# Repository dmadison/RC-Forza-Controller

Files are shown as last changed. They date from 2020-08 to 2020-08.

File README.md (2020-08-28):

# RC Controller for Forza
This project converts a DUMBORC x4 remote control for an RC car into a controller for [Forza Horizon 4](https://forzamotorsport.net/en-us/games/fh4). A USB-capable microcontroller reads the receiver's PWM pulses and translates the signals into Xbox controller (XInput) inputs for the game.

For more information, check out the article on [PartsNotIncluded.com](https://www.partsnotincluded.com/modifying-an-rc-controller-to-play-forza-horizon).

## Dependencies
The microcontroller code has several dependencies:

* [ArduinoXInput](https://github.com/dmadison/ArduinoXInput) [(v1.2.3)](https://github.com/dmadison/ArduinoXInput/releases/tag/v1.2.3)
* [ServoInput](https://github.com/dmadison/ServoInput) [(v1.0.0)](https://github.com/dmadison/ServoInput/releases/tag/v1.0.0)
* [ArduinoXInput AVR Core](https://github.com/dmadison/ArduinoXInput_AVR) [(v1.0.1)](https://github.com/dmadison/ArduinoXInput_AVR/releases/tag/v1.0.1)

I've linked to the specific releases that work with this code. Note that other versions may not be compatible.

This project was compiled using version 1.8.12 of the Arduino IDE. Microcontrollers other than the ATmega32U4 may be compatible but have not been tested.

## License
This project is licensed under the terms of the [GNU General Public License](https://www.gnu.org/licenses/gpl-3.0.en.html), either version 3 of the License, or (at your option) any later version.

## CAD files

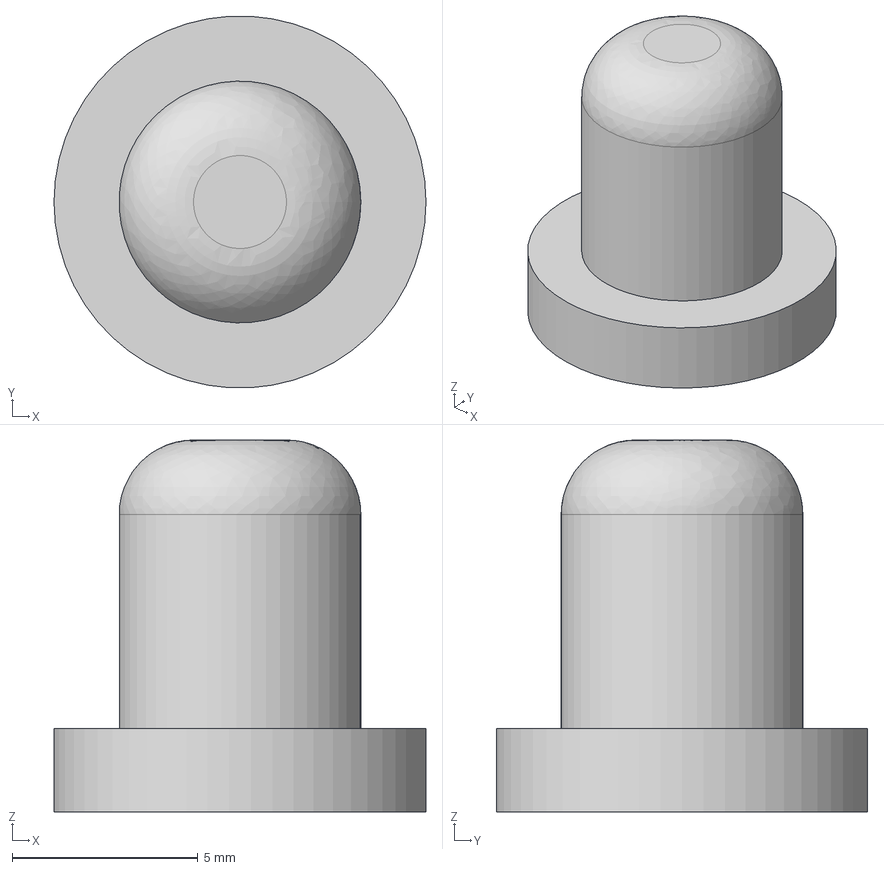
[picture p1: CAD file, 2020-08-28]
cad/CH 5-6 Button Insert/CH5-6 Button Insert.step
10.0 x 9.98 x 10.0 mm

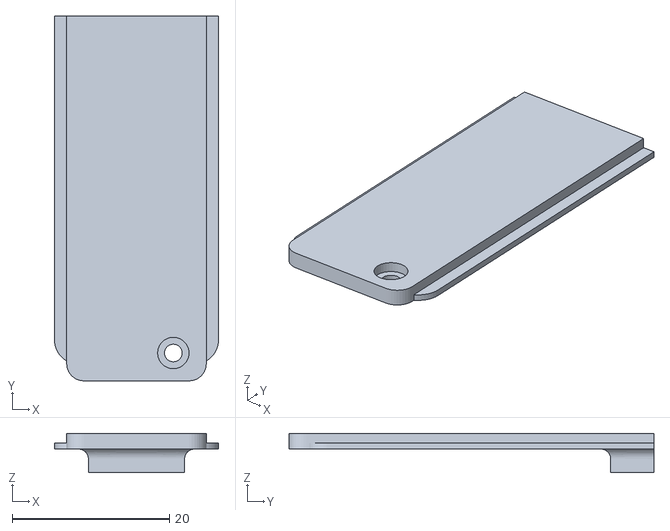
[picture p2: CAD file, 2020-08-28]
cad/Receiver Case/RC-Receiver_Cover.stl
20.9 x 46.4 x 5.00

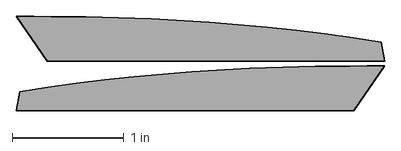
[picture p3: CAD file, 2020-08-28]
decals/DumboRC_Grip-Base-Strip.dxf
3.30 x 0.843 in

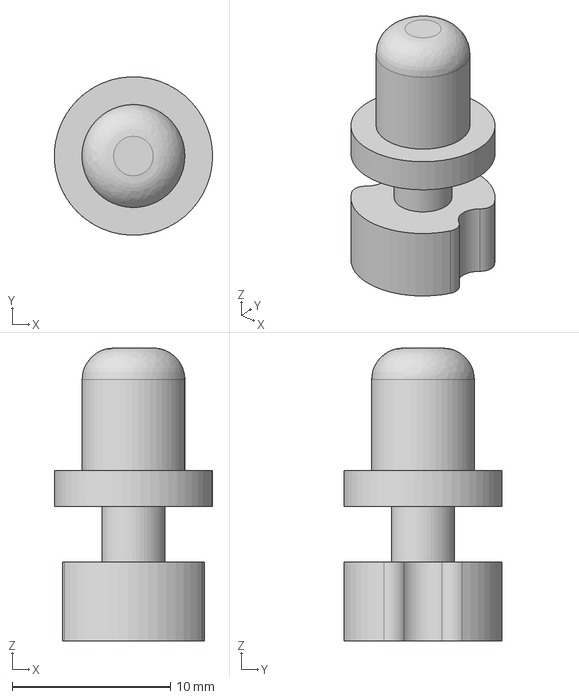
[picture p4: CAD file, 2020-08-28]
cad/CH 5-6 Button Insert/CH5-6 Button Insert with Hanger.step
9.99 x 10.00 x 18.5 mm

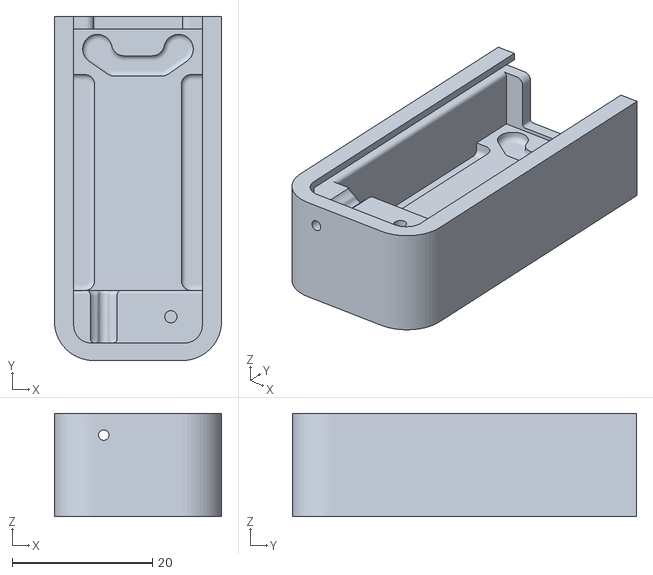
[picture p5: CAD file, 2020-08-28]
cad/Receiver Case/RC-Receiver_Base.stl
23.9 x 49.1 x 14.8

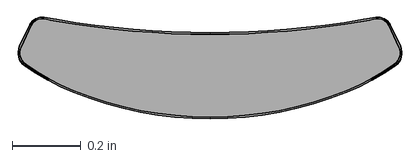
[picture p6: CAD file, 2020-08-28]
decals/DumboRC_Adjustment-Insert.dxf
1.13 x 0.299 in

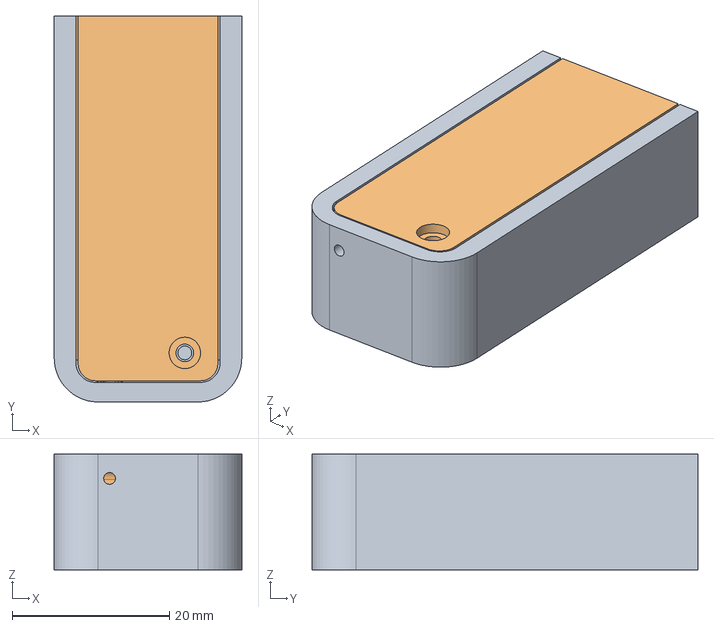
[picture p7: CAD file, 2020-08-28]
cad/Receiver Case/RC-Receiver_Case.step
23.9 x 49.1 x 14.8 mm

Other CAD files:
cad/CH 5-6 Button Insert/CH5-6 Button Insert with Hanger.stl
cad/CH 5-6 Button Insert/CH5-6 Button Insert.stl

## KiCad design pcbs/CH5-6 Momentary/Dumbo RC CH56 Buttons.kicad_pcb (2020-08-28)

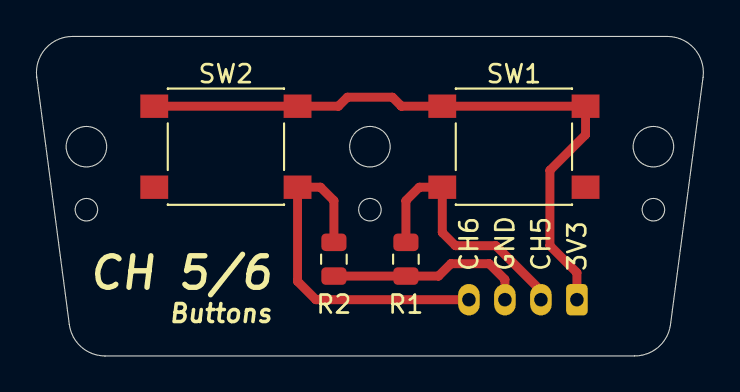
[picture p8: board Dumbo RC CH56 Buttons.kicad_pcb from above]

Board: 2 copper layers, 37.1 x 17.8 mm, 11 parts (1 on the bottom side), 4 nets.

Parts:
H1, H2, H3: MountingHole; MountingHole_2.25mm
H4, H5, H6: AlignmentHole; AlignmentHole_1.25mm
J1: Conn_01x04; JST_PH_B4B-PH-K_1x04_P2.00mm_Vertical
R1, R2: 10k; R_0805_2012Metric
SW1, SW2: SW_Push; SW_SPST_PTS645

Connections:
/3V3: J1.1, SW1.1, SW2.1
/CH5: J1.2, R1.1, SW1.2
/CH6: J1.4, R2.1, SW2.2
GND: J1.3, R1.2, R2.2

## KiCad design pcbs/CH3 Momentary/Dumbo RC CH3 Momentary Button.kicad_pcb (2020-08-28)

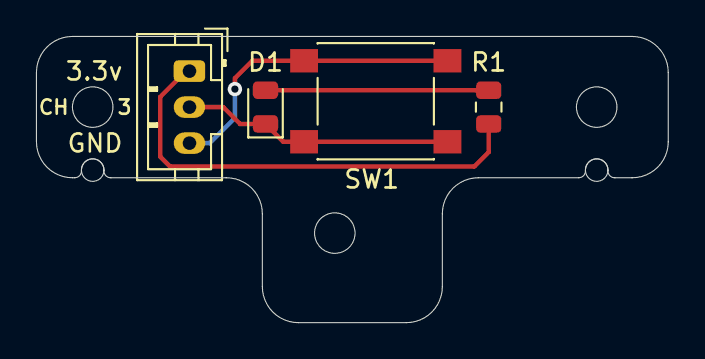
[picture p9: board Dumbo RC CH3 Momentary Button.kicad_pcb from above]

Board: 2 copper layers, 35.1 x 15.9 mm, 9 parts (0 on the bottom side), 4 nets.

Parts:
D1: LED; LED_0805_2012Metric
H1, H2, H3: MountingHole; MountingHole_2.25mm
H4, H5: AlignmentHole; AlignmentHole_1.25mm
J1: Conn_01x03; JST_PH_B3B-PH-K_1x03_P2.00mm_Vertical
R1: 330 Ω; R_0805_2012Metric
SW1: SW_Push; SW_SPST_PTS645

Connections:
/3V3: J1.1, R1.2
/CH3: D1.1, J1.2, SW1.2
/GND: J1.3, SW1.1
unnamed: D1.2, R1.1

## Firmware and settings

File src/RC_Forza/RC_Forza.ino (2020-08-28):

/*
*  Project     RC Forza Controller
*  @author     David Madison
*  @link       github.com/dmadison/RC-Forza-Controller
*  @license    GPLv3 - Copyright (c) 2020 David Madison
*
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
*/

#if defined(__AVR_ATmega32U4__)  // Arduino Pro Micro / Leonardo
	#define SERVOINPUT_SUPPRESS_WARNINGS  // enables the use of pin change interrupts in the library
	#define USING_PCINT  // enables the pin change interrupt setup
#endif

#include <ServoInput.h>
#include <XInput.h>

// ServoInput objects, one for each channel
ServoInputPin<0> ch1;  // steering wheel
ServoInputPin<1> ch2;  // speed trigger
ServoInputPin<2> ch3;  // momentary button on grip
ServoInputPin<3> ch4;  // slide switch on grip
ServoInputPin<7> ch5;  // momentary button on top (left)
ServoInputPin<8> ch6;  // momentary button on top (right), PCINT

// Deadzone settings, as a percentage of the total range (applied at center)
const float Deadzone_Steering = 0.15;
const float Deadzone_Throttle = 0.10;

const int16_t ButtonThreshold = 10000;  // ~1/3rd rotation past deadzone (int16_t range)

enum class RC_Mode{
	Extras = 0,
	Race = 1,
	Menu = 2,
} mode = RC_Mode::Race;

#ifdef USING_PCINT
	void setupPCINT() {
		const uint8_t pin = ch6.getPin();
		*digitalPinToPCMSK(pin) |= bit(digitalPinToPCMSKbit(pin));  // enable pin
		PCIFR |= bit(digitalPinToPCICRbit(pin)); // clear any outstanding interrupt
		PCICR |= bit(digitalPinToPCICRbit(pin)); // enable interrupt for the group
	}

	ISR(PCINT0_vect) {  // pin change ISR handler
		ch6.isr();
	}
#else
	void setupPCINT() {}
#endif


void setup() {
	setupPCINT();  // pin change interrupt needed for pin 8 on 32U4

	XInput.setAutoSend(false);
	XInput.begin();

	while (!ServoInput.allAvailable()) {  // wait for all channels to be ready
		Serial.println("Waiting for signals...");
	}
}

void loop() {
	bootloaderCheck();
	modeCheck();

	switch (mode) {
		case(RC_Mode::Race):
			raceMode();
			break;
		case(RC_Mode::Extras):
			extrasMode();
			break;
		case(RC_Mode::Menu):
			menuMode();
			break;
	}

	XInput.send();
}

void modeCheck() {
	static const uint8_t CountThreshold = 5;  // number of updates before switching, 20 ms each (100 ms total)
	static RC_Mode changeMode = mode;  // mode we're working towards
	static uint8_t changeCount = 0;  // # of updates using the new mode

	if (!ch4.available()) return;  // no new data

	RC_Mode newMode = (RC_Mode) ch4.map(0, 2);  // change mode depending on slide position

	if (newMode != mode) {  // mode is different
		if (newMode != changeMode) {
			changeMode = newMode;  // we're working towards *this*
			changeCount = 0;  // reset count
		}
		changeCount++;  // increment count

		if (changeCount >= CountThreshold) {
			XInput.releaseAll();  // clear existing controls
			mode = newMode;
		}
	}
	else {
		changeCount = 0;  // mode is the same, hold count at 0
	}
}


int16_t getServoJoy(ServoInputSignal& sig, float dz, boolean invert = false) {
	int16_t axis = sig.mapDeadzone(-32767, 32767, dz);  // symmetrical range w/ deadzone at '0'.
	if (invert) axis = -axis;
	if (axis == -32767) axis = -32768;  // edge case, max value
	return axis;
}

void setTriggerAxis(int16_t val) {
	// set both the left and right triggers based on a single value (-255 to 255)

	if (val < -255) val = -255;
	else if (val > 255) val = 255;

	uint8_t lt = 0, rt = 0;
	if (val < 0) lt = abs(val);  // less than 0, send to left trigger
	else rt = (uint8_t) val;  // greater than 0, send to right trigger

	XInput.setTrigger(TRIGGER_LEFT, lt);
	XInput.setTrigger(TRIGGER_RIGHT, rt);
}

void raceMode() {
	// CH1: Steering (Left Joy X)
	int16_t steering = getServoJoy(ch1, Deadzone_Steering, true);
	XInput.setJoystickX(JOY_LEFT, steering);

	// CH2: Gas & Brake (Triggers)
	int16_t throttle = ch2.mapDeadzone(-255, 255, Deadzone_Throttle);
	setTriggerAxis(throttle);

	// CH3: Handbrake (A)
	boolean handbrake = !ch3.getBoolean();  // active low
	XInput.setButton(BUTTON_A, handbrake);

	// CH5: Horn (R3)
	boolean horn = ch5.getBoolean();
	XInput.setButton(BUTTON_R3, horn);

	// CH6: Enter Event (X)
	boolean enterEvent = ch6.getBoolean();
	XInput.setButton(BUTTON_X, enterEvent);
}

void menuMode() {
	// CH3: Alternate Inputs
	boolean altInputs = !ch3.getBoolean();  // active low

	// CH1: Menu Navigation X (Left Joy X) | Alt: LB/RB
	int16_t steering = getServoJoy(ch1, Deadzone_Steering, true);

	int16_t menuX   = !altInputs ? steering : 0;
	int16_t bumpers = altInputs ? steering : 0;
	
	XInput.setJoystickX(JOY_LEFT, menuX);
	XInput.setButton(BUTTON_LB, bumpers <= -ButtonThreshold);
	XInput.setButton(BUTTON_RB, bumpers >= ButtonThreshold);

	// CH2: Menu Navigation Y (Left Joy Y) | Alt: Map Zoom (Right Joy Y)
	int16_t throttle = getServoJoy(ch2, Deadzone_Throttle);

	int16_t moveY = !altInputs ? throttle : 0;
	int16_t zoomY =  altInputs ? throttle : 0;

	XInput.setJoystickY(JOY_LEFT, moveY);
	XInput.setJoystickY(JOY_RIGHT, zoomY);

	// CH5: Cancel (B) | Alt: Map (Back)
	boolean topLeft = ch5.getBoolean();

	boolean cancel = topLeft && !altInputs;
	boolean map    = topLeft &&  altInputs;

	XInput.setButton(BUTTON_B, cancel);
	XInput.setButton(BUTTON_BACK, map);

	// CH6: Confirm (A) | Alt: Menu (Start)
	boolean topRight = ch6.getBoolean();

	boolean confirm = topRight && !altInputs;
	boolean start   = topRight &&  altInputs;

	XInput.setButton(BUTTON_A, confirm);
	XInput.setButton(BUTTON_START, start);
}

void extrasMode() {
	// CH3: Alternate Inputs
	boolean altInputs = !ch3.getBoolean();  // active low

	// CH1: DPAD Left/Right | Alt: Horizontal Camera (Right Joy X)
	int16_t steering = getServoJoy(ch1, Deadzone_Steering, true);

	int16_t dpadX   = !altInputs ? steering : 0;
	int16_t cameraX =  altInputs ? steering : 0;

	XInput.setButton(DPAD_LEFT,  dpadX <= -ButtonThreshold);
	XInput.setButton(DPAD_RIGHT, dpadX >= ButtonThreshold);
	XInput.setJoystickX(JOY_RIGHT, cameraX);

	// CH2: DPAD Up/Down | Alt: Veritcal Camera (Right Joy Y)
	int16_t throttle = getServoJoy(ch2, Deadzone_Throttle);

	int16_t dpadY   = !altInputs ? throttle : 0;
	int16_t cameraY =  altInputs ? throttle : 0;

	XInput.setButton(DPAD_DOWN, dpadY <= -ButtonThreshold);
	XInput.setButton(DPAD_UP,   dpadY >= ButtonThreshold);
	XInput.setJoystickY(JOY_RIGHT, cameraY);

	// CH5: Change Camera View (RB)
	boolean camera = ch5.getBoolean();
	XInput.setButton(BUTTON_RB, camera);

	// CH6: Rewind (Y)
	boolean rewind = ch6.getBoolean();
	XInput.setButton(BUTTON_Y, rewind);
}

void printDebug() {
	ServoInputSignal* ptr = ServoInputSignal::getHead();
	uint8_t ch = 1;

	while (ptr != nullptr) {
		char buffer[12] = {};

		sprintf(buffer, "%u: %4u us\t", ch++, (uint16_t) ptr->getPulseRaw());
		Serial.print(buffer);

		ptr = ptr->getNext();
	}
	Serial.println();
}

void bootloaderCheck() {
	/* Since XInput disables the standard upload process, here's an alternate
	 * method without having to open up the case and double-tap the reset pin.
	 * Just hold all three buttons (Ch3, Ch5, and Ch6) for 7 seconds.
	 */

	static const unsigned long HoldTime = 7000;  // ms (7 s)
	static unsigned long lastRelease = 0;

	boolean b1 = !ch3.getBoolean();  // Ch3 (grip) - active low
	boolean b2 = ch5.getBoolean();   // Ch5 (top left)
	boolean b3 = ch6.getBoolean();   // Ch6 (top right)

	if (b1 && b2 && b3) {
		if (millis() - lastRelease >= HoldTime) {
			resetBoard();  // jump to bootloader
		}
	}
	else {
		lastRelease = millis();  // any button released
	}
}

void resetBoard() {
#ifdef __AVR_ATmega32U4__
	// Basic structure borrowed from Teensy 2.0: 
	// https://github.com/PaulStoffregen/cores/blob/fc79132670ac83ce7cae8e2bac64be109fbfe35e/teensy/pins_teensy.c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

	// disable interrupts
	cli();

	// stop watchdog timer, if running
	MCUSR &= ~(1 << WDRF);   // clear "Watchdot Reset Flag" (WDRF) bit (set 0)
	WDTCSR |= (1 << WDCE);   // set "Watchdog Change Enable" (WDCE) bit to 1
	WDTCSR = 0;              // clear "Watchdog Timer Control Register" (WDTCSR)
	_delay_ms(5);            // wait for watchdog change to clear

	// disconnect from USB
	UDCON = 1;               // set "Detach Bit" to disconnect the device
	USBCON = (1 << FRZCLK);  // set the "Freeze USB Clock" bit to disable USB interrupts
	_delay_ms(15);           // wait for USB to disconnect

	// disable peripherals
	EIMSK = 0;   // disable external interrupts (External Interrupt Mask Register)
	PCICR = 0;   // disable pin change interrupts (Pin Change Interrupt Control Register)
	SPCR = 0;    // disable SPI (SPI Control Register)
	ACSR = 0;    // disable analog comparator (Analog Comparator Control and Status Register)
	EECR = 0;    // disable EEPROM writing (EEPROM Control Register)
	ADCSRA = 0;  // disable ADC (ADC Control and Status Register A)
	TIMSK0 = 0;  // disable timer0 interrupts (Timer/Counter Interrupt Mask Register)
	TIMSK1 = 0;  // disable timer1 interrupts (Timer/Counter1 Interrupt Mask Register)
	TIMSK3 = 0;  // disable timer3 interrupts (Timer/Counter3 Interrupt Mask Register)
	TIMSK4 = 0;  // disable timer4 interrupts (Timer/Counter4 Interrupt Mask Register)
	UCSR1B = 0;  // disable USART 1 (USART MSPIM Control and Status Register n B)
	TWCR = 0;    // disable I2C
	DDRB = 0;    // set PORTB pins to "input"
	DDRC = 0;    // set PORTC pins to "input"
	DDRD = 0;    // set PORTD pins to "input"
	DDRE = 0;    // set PORTE pins to "input"
	DDRF = 0;    // set PORTF pins to "input"
	PORTB = 0;   // disable PORTB internal pull-ups
	PORTC = 0;   // disable PORTC internal pull-ups
	PORTD = 0;   // disable PORTD internal pull-ups
	PORTE = 0;   // disable PORTE internal pull-ups
	PORTF = 0;   // disable PORTF internal pull-ups

	// jump to the bootloader address
	// with BOOTSZ fuse = 0x00 (2040 words):
	//     32,768 - 2048 * 2 = 28,672, or 0x7000 in hex
	__asm__ volatile("jmp 0x7000");
	while (1);
#endif
}

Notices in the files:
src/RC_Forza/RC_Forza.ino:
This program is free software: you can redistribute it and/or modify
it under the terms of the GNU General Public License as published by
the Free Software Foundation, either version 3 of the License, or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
